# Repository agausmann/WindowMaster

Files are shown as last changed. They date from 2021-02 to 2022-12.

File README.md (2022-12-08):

# WindowMaster

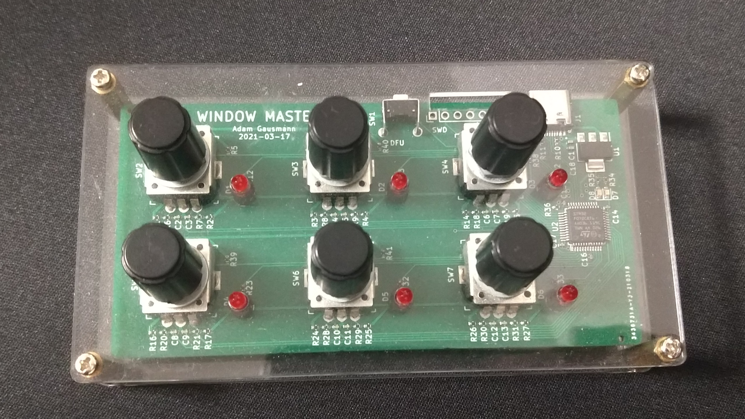
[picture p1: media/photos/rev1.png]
WindowMaster Rev1


A physical controller for the Windows Volume Mixer (sndvol).

This project is made up of multiple hardware and software parts:

- `pcb/` - KiCad design files for the controller PCB.

- `case/` - A laser-cut acrylic case for the PCB.

- `firmware/` - Firmware running on the controller.

- `host-controller/` (**WIP**) - PC software to bridge between the controller
  and the system volume mixer.

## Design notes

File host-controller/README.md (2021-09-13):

# Host Controller Software

**This is a Work in Progress.** The core of the application is nearly complete, but I would not
consider it ready for general use, because it is lacking GUI elements that are very important for
a good user experience.

However, if you would like to try it out, you can run it on the command line. You will, of course,
need a WindowMaster device to interface with the application (though support for MIDI control
surfaces may come in the future).

Make sure you have the [Rust toolchain](https://www.rust-lang.org/tools/install) installed, and
then clone and run with:

```sh
git clone https://github.com/agausmann/windowmaster.git
cd windowmaster/host-controller
cargo run
```

You can set bindings on each channel by pressing the knob down until its LED starts blinking.
The menu will be printed on the console. Navigate by rotating the knob, and select by pressing.
Then, the knob can be used to control the volume and mute of that device or application.
Long-press again at any time to open the menu and re-bind the channel.

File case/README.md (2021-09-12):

# Case Files

The case is made from two laser-cut acrylic parts, the top and bottom plate.
The top plate has holes for the encoders, LEDs, and the ST-Link header, and it
is mounted to the PCB by the fasteners on the encoder stems. The bottom plate
has holes to access the DFU/Reset buttons on the back of the PCB, and is
attached to the front plate with M2.5 bolts and 15mm standoffs.

I've provided the OpenSCAD models and the SVGs generated from them, one for the
top plate, and one for the bottom plate. The SVGs can be provided to a
laser-cutting service like Ponoko; I'd recommend using 2mm clear acrylic
sheets. The dimensions in the SVG files are in millimeters.

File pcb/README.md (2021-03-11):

# WindowMaster PCB

This circuit board is the main board for the WindowMaster physcial controller.
It supports 6 control channels which can be individually assigned to different
channels via the WindowMaster software.

The MCU powering this board is an [STM32F072C8], which can read the encoder
states and set indicators via GPIO, and communicate with the host computer over
USB. You can flash the provided firmware to communicate with and control the
WindowMaster host software, or write and flash your own if you have another
usecase for the control surface. (In the future, I may provide other firmwares
to turn it into a generic input device like a joystick or MIDI. Feel free to
contact me if you'd like to commission a custom firmware - I'd love to hear
about your idea!)

This board is developed with KiCad version 5.1.9. Components, especially those
that can or must be surface-mounted, are picked from the [JLCPCB SMT Parts
Library](https://jlcpcb.com/parts), if there is a suitable part there. This
makes it more convenient to fabricate and assemble, as they will do most of the
work. Everything else is picked to be easy to hand-solder with an iron, which
generally means through-hole or large tabs.

## Ordering

TODO

## Programming Reference & Pinout

The PCB is laid out into six channels. Each channel has its own quadrature
encoder (PEC11R), a pushbutton switch (built into the encoder), and an
indicator LED. These peripherals are controlled by the onboard [STM32F072C8]
microcontroller, which is also given a USB port so it can communicate with a
host system.

Here is the pinout of the STM32 chip to all of its connected peripherals, for
quick reference while programming:

| Physical | Logical | Description | Direction | Logic |
|---|---|---|---|---|
| 25 | PB12 | Status LED | Output | Active Low |
| 32 | PA11 | USB D- | | |
| 33 | PA12 | USB D+ | | |
| 3 | PC14 | Channel 1 Encoder A  | Input | Active Low |
| 2 | PC13 | Channel 1 Encoder B  | Input | Active Low |
| 39 | PB3 | Channel 1 Pushbutton | Input | Active Low |
| 40 | PB4 | Channel 1 Indicator  | Output | Active Low |
| 46 | PB9 | Channel 2 Encoder A  | Input | Active Low |
| 45 | PB8 | Channel 2 Encoder B  | Input | Active Low |
| 38 | PA15 | Channel 2 Pushbutton | Input | Active Low |
| 41 | PB5 | Channel 2 Indicator  | Output | Active Low |
| 43 | PB7 | Channel 3 Encoder A  | Input | Active Low |
| 42 | PB6 | Channel 3 Encoder B  | Input | Active Low |
| 27 | PB14 | Channel 3 Pushbutton | Input | Active Low |
| 28 | PB15 | Channel 3 Indicator  | Output | Active Low |
| 18 | PB0 | Channel 4 Encoder A  | Input | Active Low |
| 17 | PA7 | Channel 4 Encoder B  | Input | Active Low |
| 6 | PF1 | Channel 4 Pushbutton | Input | Active Low |
| 10 | PA0 | Channel 4 Indicator  | Output | Active Low |
| 16 | PA6 | Channel 5 Encoder A  | Input | Active Low |
| 15 | PA5 | Channel 5 Encoder B  | Input | Active Low |
| 5 | PF0 | Channel 5 Pushbutton | Input | Active Low |
| 11 | PA1 | Channel 5 Indicator  | Output | Active Low |
| 14 | PA4 | Channel 6 Encoder A  | Input | Active Low |
| 13 | PA3 | Channel 6 Encoder B  | Input | Active Low |
| 4 | PC15 | Channel 6 Pushbutton | Input | Active Low |
| 12 | PA2 | Channel 6 Indicator  | Output | Active Low |

## Flashing

The focus of this section will be on the specifics of flashing on this board. I
expect the reader to know generally how to program STM32 devices; there's plenty
of other resources on the Internet that explain it better than I ever could.

There are two ways that the STM32 chip can be flashed: the USB DFU protocol,
and the ST-Link debug interface.

### USB DFU

To start the device in DFU mode:  While holding down the DFU button, connect
the USB cable so that it powers on and connects to the computer. Once it has
turned on, you can let go of DFU.

(_Note_: If the device is already connected, you can enter DFU mode without
disconnecting by holding down DFU and pressing and releasing RESET. Again, you
can release DFU once it has reset.)

Once the device is in DFU mode, you can use a tool like [DfuSe] or [dfu-util] on
the host computer to connect to the device and flash firmware binaries.

### ST-Link

There is a spot for an ST-Link / SWD breakout header at the top of the PCB, in
between the reset switch and USB port. The pinout of that port is designed to
match the SWD header on Discovery/Nucleo boards, so from left to right:

1. 3v3 power (not connected in rev1, you have to supply power over USB)
2. SWCLK
3. GND
4. SWDIO
5. NRST
6. Not connected (normally SWO, which is unsupported by this chip).

Connect an ST-Link to that header, and connect both the ST-Link and the PCB to
the computer via USB. Then you can flash using whatever ST-Link compatible tool
or method you prefer. (openOCD, cargo-flash, etc)

[STM32F072C8]: https://www.st.com/en/microcontrollers-microprocessors/stm32f072c8.html
[DfuSe]: https://www.st.com/en/development-tools/stsw-stm32080.html#overview
[dfu-util]: http://dfu-util.sourceforge.net/

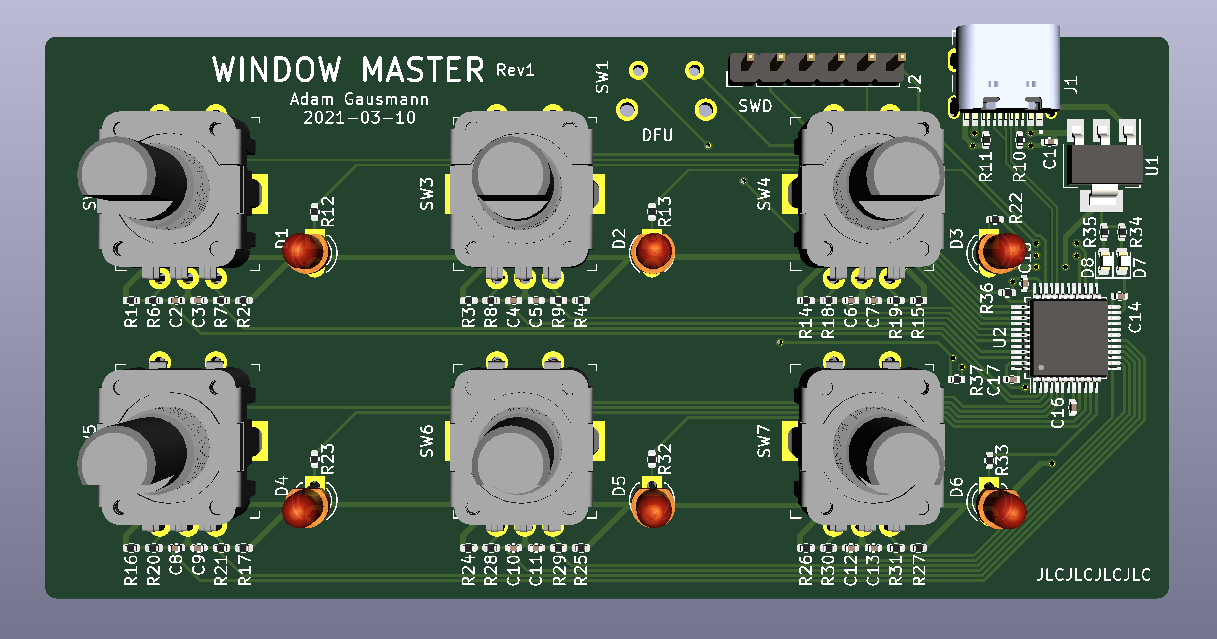
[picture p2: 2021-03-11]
media/renders/pcb-front.png

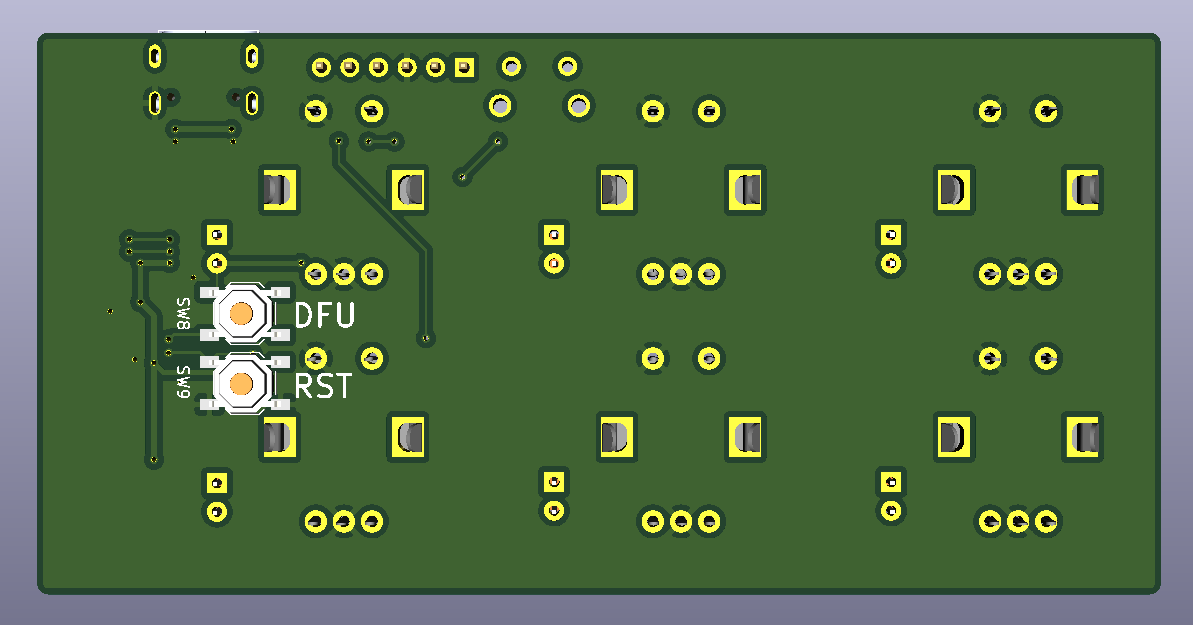
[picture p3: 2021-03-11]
media/renders/pcb-back.png

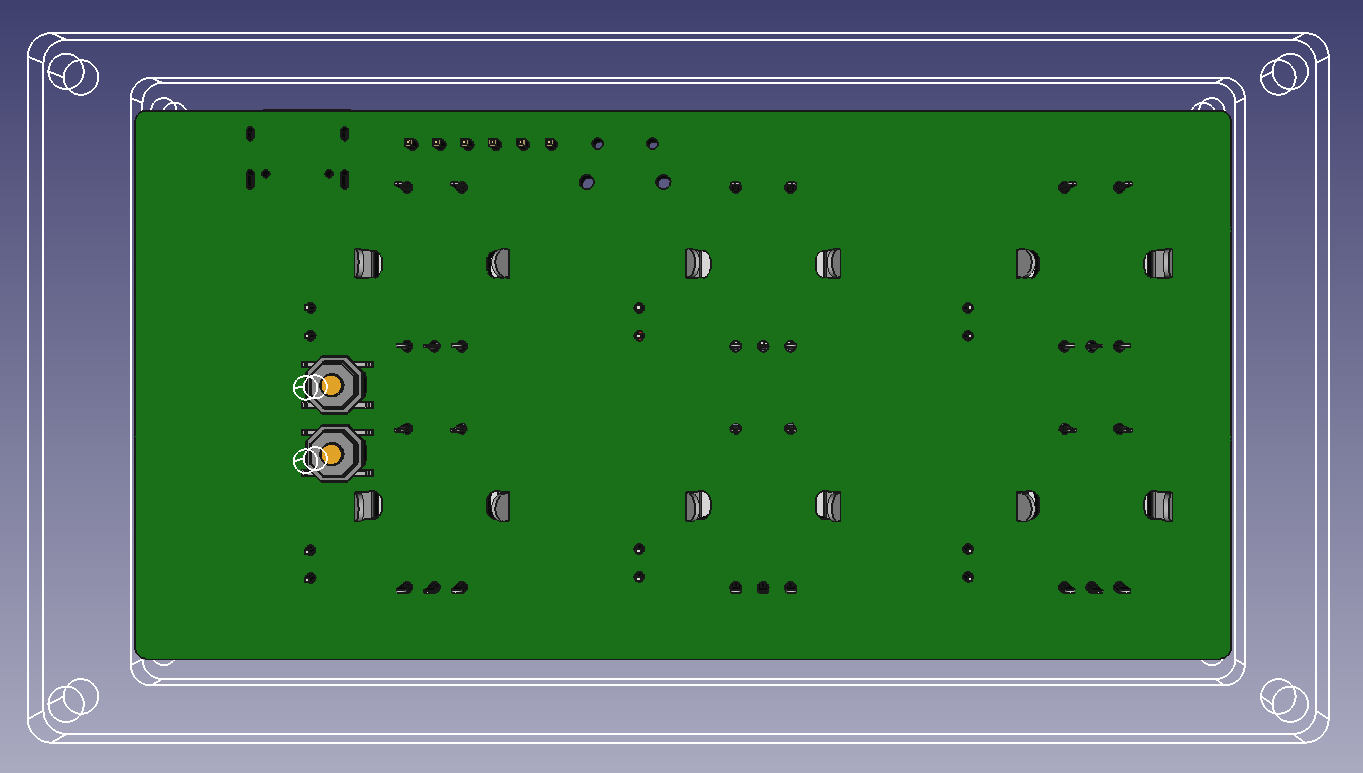
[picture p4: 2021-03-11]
media/renders/cad-back.png

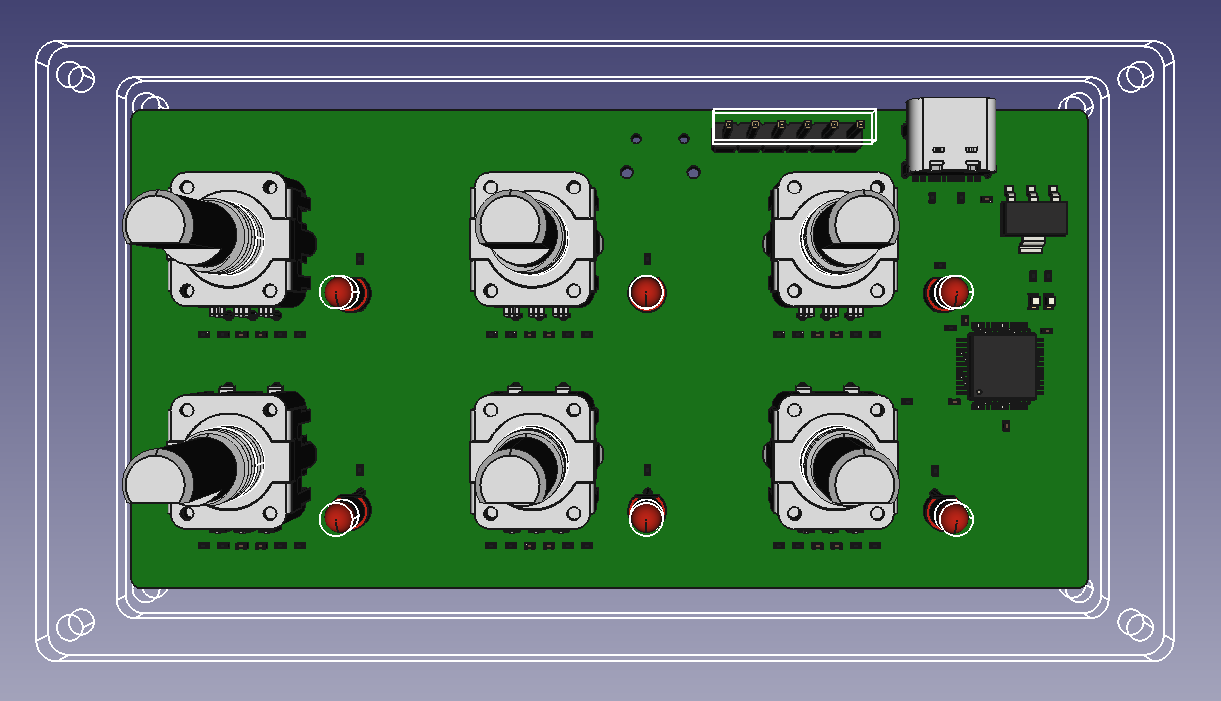
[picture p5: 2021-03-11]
media/renders/cad-front.png

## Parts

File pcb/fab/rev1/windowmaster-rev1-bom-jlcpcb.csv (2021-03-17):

Comment | Designator | Footprint | LCSC Part #
4.7uF | C1,C18 | 0402 | C23733
10nF | C2-13 | 0402 | C15195
100nF | C14-17 | 0402 | C1525
PWR_LED | D7 | 0603 | C72043
STATUS_LED | D8 | 0603 | C72038
USB_C_Receptacle_USB2.0 | J1 |  | C165948
5.1K | R10,R11 | 0402 | C25905
1K | R12, R13, R22, R23, R32-35 | 0402 | C11702
10K | R1-9, R14-21, R24-31, R36-42 | 0402 | C25744
AZ1117-3.3 | U1 | SOT-223 | C108494
STM32F072C8T6 | U2 | LQFP-48_7.0x7.0x0.5P | C80488

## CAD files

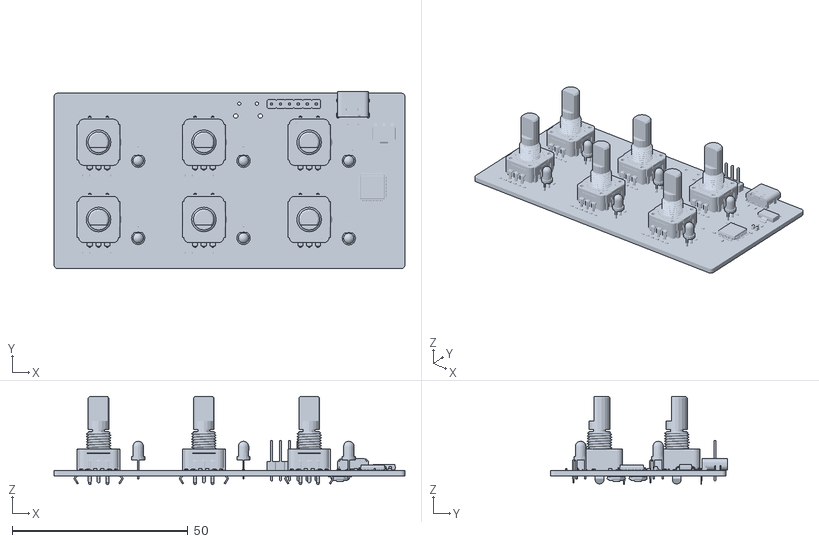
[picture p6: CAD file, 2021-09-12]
case/windowmaster.stl
100.0 x 50.5 x 25.2

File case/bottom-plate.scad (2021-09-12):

use <plate.scad>

$fa = 1;
$fs = 0.4;

module bottom_plate() {
    difference() {
        plate();

        // Reset/DFU button holes
        translate([86.5, 30])
            circle(r=1);
        translate([86.5, 23.5])
            circle(r=1);
    }
}

bottom_plate();

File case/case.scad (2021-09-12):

// A full model (including the PCB model) to demonstrate the assembled case
// and visually verify the plate drawings.
//
// To order parts for this case, use the `top-plate` and `bottom-plate` files
// instead of this model.

use <top-plate.scad>
use <bottom-plate.scad>

plate_thickness = 2;
standoff_height = 15;

module case() {
    color([1, 1, 1, 0.2]) {
        linear_extrude(plate_thickness)
            top_plate();
        translate([0, 0, -(standoff_height + plate_thickness)])
            linear_extrude(plate_thickness)
                bottom_plate();
    }
    translate([55, 30, -8])
        import("windowmaster.stl");
}

case();

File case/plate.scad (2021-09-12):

// Base plate module used for both bottom & top plates.

width = 110;
height = 60;
radius = 2;
screw_radius = 1.25;
screw_inset = 3.25;

module plate() {
    difference() {
        translate([radius, radius])
            minkowski() {
                square([width - 2 * radius, height - 2 * radius]);
                circle(r=radius);
            }

        translate([screw_inset, screw_inset])
            circle(r=screw_radius);        
        translate([screw_inset, height - screw_inset])
            circle(r=screw_radius);
        translate([width - screw_inset, screw_inset])
            circle(r=screw_radius);
        translate([width - screw_inset, height - screw_inset])
            circle(r=screw_radius);
    }
}

plate();

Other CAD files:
pcb/snap_eda/pec11r-4015f-s0024.stp
pcb/windowmaster.step
pcb/snap_eda/TYPE-C-31-M-12.step
case/top-plate.scad

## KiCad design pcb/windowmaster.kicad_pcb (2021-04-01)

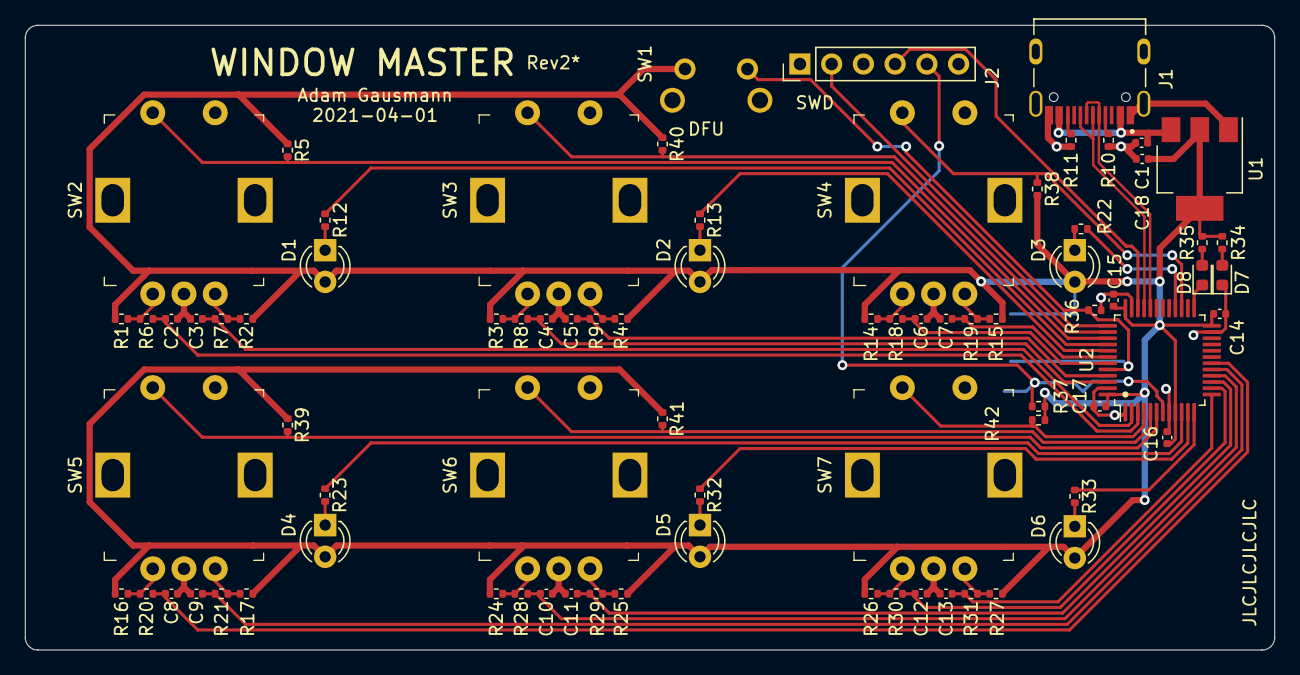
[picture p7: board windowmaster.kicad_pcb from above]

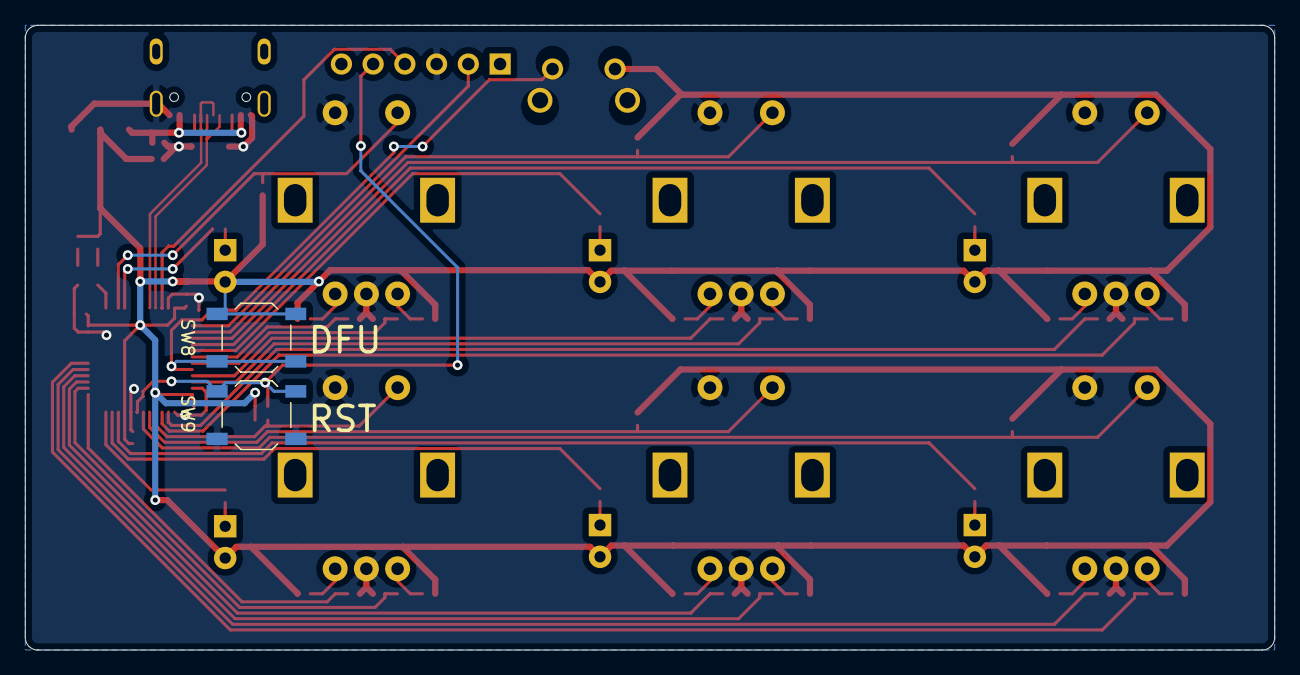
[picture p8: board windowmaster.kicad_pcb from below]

Board: 2 copper layers, 100.0 x 50.0 mm, 81 parts (2 on the bottom side), 56 nets.

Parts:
C1, C18: 4.7uF; C_0402_1005Metric
C2, C3, C4, C5, C6, C7, C8, C9, C10, C11, C12, C13: 10nF; C_0402_1005Metric
C14, C15, C16, C17: 100nF; C_0402_1005Metric
D1, D2, D3, D4, D5, D6: LED; LED_D3.0mm
D7: PWR_LED; LED_0603_1608Metric
D8: STATUS_LED; LED_0603_1608Metric
J1: USB_C_Receptacle_USB2.0; HRO_TYPE-C-31-M-12
J2: SWD; PinHeader_1x06_P2.54mm_Vertical
R1, R2, R3, R4, R5, R6, R7, R8, R9, R14, R15, R16, R17, R18, R19, R20, R21, R24, R25, R26, R27, R28, R29, R30, R31, R36, R37, R38, R39, R40, R41, R42: 10K; R_0402_1005Metric
R10, R11: 5.1K; R_0402_1005Metric
R12, R13, R22, R23, R32, R33, R34, R35: 1K; R_0402_1005Metric
SW1: SW_DFU2; MJTP1117
SW2, SW3, SW4, SW5, SW6, SW7: ENC; Rotary_Encoder_Switched_PEC11R
SW8: SW_DFU; SW_SPST_TL3342
SW9: SW_RST; SW_SPST_TL3342
U1: AZ1117-3.3; SOT-223-3_TabPin2
U2: STM32F072C8T6; LQFP-48_7x7mm_P0.5mm

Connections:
+3V3: C14.1, C15.1, C16.1, C17.1, C18.1, D1.2, D2.2, D3.2, D4.2, D5.2, D6.2, R1.1, R2.1, R3.1, R4.1, R5.1, R14.1, R15.1, R16.1, R17.1, R24.1, R25.1, R26.1, R27.1, R34.1, R35.1, R37.1, R38.1, R39.1, R40.1, R41.1, R42.1, SW1.2, SW8.1, U1.2, U2.9, U2.24, U2.36, U2.48
DFU: R36.1, SW1.1, SW8.2, U2.44
ENC_1A: C2.1, R6.2, U2.3
ENC_1B: C3.1, R7.2, U2.2
ENC_2A: C4.1, R8.2, U2.46
ENC_2B: C5.1, R9.2, U2.45
ENC_3A: C6.1, R18.2, U2.43
ENC_3B: C7.1, R19.2, U2.42
ENC_4A: C8.1, R20.2, U2.18
ENC_4B: C9.1, R21.2, U2.17
ENC_5A: C10.1, R28.2, U2.16
ENC_5B: C11.1, R29.2, U2.15
ENC_6A: C12.1, R30.2, U2.14
ENC_6B: C13.1, R31.2, U2.13
GND: C1.2, C2.2, C3.2, C4.2, C5.2, C6.2, C7.2, C8.2, C9.2, C10.2, C11.2, C12.2, C13.2, C14.2, C15.2, C16.2, C17.2, C18.2, D7.1, J1.A1, J1.A12, J1.B1, J1.B12, J1.S1, J2.3, R10.1, R11.1, R36.2, SW2.C, SW2.S2, SW3.C, SW3.S2, SW4.C, SW4.S2, SW5.C, SW5.S2, SW6.C, SW6.S2, SW7.C, SW7.S2, SW9.2, U1.1, U2.1, U2.8, U2.23, U2.35, U2.47
IND_1: R12.1, U2.40
IND_2: R13.1, U2.41
IND_3: R22.1, U2.28
IND_4: R23.1, U2.10
IND_5: R32.1, U2.11
IND_6: R33.1, U2.12
NRST: J2.5, R37.2, SW9.1, U2.7
unnamed: D1.1, R12.2
unnamed: D2.1, R13.2
unnamed: D3.1, R22.2
unnamed: D4.1, R23.2
unnamed: D5.1, R32.2
unnamed: D6.1, R33.2
unnamed: D7.2, R34.2
unnamed: D8.2, R35.2
unnamed: J1.A5, R10.2
unnamed: J1.B5, R11.2
unnamed: R1.2, R6.1, SW2.A
unnamed: R2.2, R7.1, SW2.B
unnamed: R3.2, R8.1, SW3.A
unnamed: R4.2, R9.1, SW3.B
unnamed: R14.2, R18.1, SW4.A
unnamed: R15.2, R19.1, SW4.B
unnamed: R16.2, R20.1, SW5.A
unnamed: R17.2, R21.1, SW5.B
unnamed: R24.2, R28.1, SW6.A
unnamed: R25.2, R29.1, SW6.B
unnamed: R26.2, R30.1, SW7.A
unnamed: R27.2, R31.1, SW7.B
STATUS: D8.1, U2.25
SWCLK: J2.2, U2.37
SWDIO: J2.4, U2.34
SW_1: R5.2, SW2.S1, U2.39
SW_2: R40.2, SW3.S1, U2.38
SW_3: R38.2, SW4.S1, U2.27
SW_4: R39.2, SW5.S1, U2.6
SW_5: R41.2, SW6.S1, U2.5
SW_6: R42.2, SW7.S1, U2.4
USB_D+: J1.A6, J1.B6, U2.33
USB_D-: J1.A7, J1.B7, U2.32
VBUS: C1.1, J1.A4, J1.A9, J1.B4, J1.B9, U1.3

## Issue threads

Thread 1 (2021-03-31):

Rev1 PCB design problems

agausmann, 2021-03-31:
- [ ] LEDs blink on poweron, because they're wired active-low and the pin goes low for a moment when set to output mode.
- [ ] Status LEDs are too bright

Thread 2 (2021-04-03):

PEC11R quality issue

agausmann, 2021-04-03:
The shaft of the PEC11R encoder has a noticeable amount of wobble. I should try out some other encoders for the next revision, see if there are better options that fit my needs.

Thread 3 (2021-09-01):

Premium/deluxe control surface

agausmann, 2021-09-01:
The current hardware was designed on a budget. I'd like to keep and maintain that as an option, but I would also like to design and produce a more high-quality device in the future.

Features I'm thinking about incorporating:

- Motorized faders
- Dedicated buttons for mute and navigation
- Integrated LCD display(s) which can be used to display labels and menus

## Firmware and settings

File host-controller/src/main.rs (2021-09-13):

use windowmaster::{
    backend::{hidapi::HidApiControlBackend, windows::WindowsAudioBackend},
    core::Core,
};

pub fn main() -> anyhow::Result<()> {
    env_logger::init();

    Core::new(WindowsAudioBackend::new(), HidApiControlBackend)
        .run()
        .map_err(|e| anyhow::anyhow!("{}", e))?;

    Ok(())
}

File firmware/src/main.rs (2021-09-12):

#![no_std]
#![cfg_attr(not(test), no_main)]
#![feature(default_alloc_error_handler)]

use alloc_cortex_m::CortexMHeap;
use core::panic::PanicInfo;
use cortex_m::interrupt::free as interrupt_free;
use cortex_m::prelude::*;
use cortex_m_rt as rt;
use stm32f0xx_hal::stm32;
use windowmaster_firmware::indicator::Indicator;

// Pick a system definition here:

use windowmaster_firmware::system::rev1 as system;
//use windowmaster_firmware::system::discovery as system;

use system::{PanicSystem, System};

#[global_allocator]
static ALLOCATOR: CortexMHeap = CortexMHeap::empty();

#[panic_handler]
fn panic(info: &PanicInfo) -> ! {
    // We are in an unrecoverable error state.
    // The regular program is not going to resume, so it is safe to take control of peripherals.
    // There might be problems here, since some of the peripherals may not be in their
    // reset state, like the PAC might assume, but I _think_ it's okay as long as the pin modes are
    // explicitly set somewhere before being used.
    let dp = unsafe { stm32::Peripherals::steal() };
    let cp = unsafe { stm32::CorePeripherals::steal() };

    let mut system = interrupt_free(|cs| PanicSystem::new(dp, cp, cs));

    system.status_led().turn_off().ok();
    for _ in 0..4 {
        system.delay().delay_ms(200u32);
        system.status_led().turn_on().ok();
        system.delay().delay_ms(200u32);
        system.status_led().turn_off().ok();
    }

    //TODO log error via debugger.
    // writing via cortex_m_semihosting tends to hang in my testing - need to look into that.

    // Error has been logged, reset the system.
    system.delay().delay_ms(1000u32);
    stm32::SCB::sys_reset()
}

#[cfg(not(test))]
#[rt::entry]
fn main() -> ! {
    let heap_start = cortex_m_rt::heap_start() as usize;
    let heap_size = 1024;
    unsafe { ALLOCATOR.init(heap_start, heap_size) }

    let dp = stm32::Peripherals::take().unwrap();
    let cp = stm32::CorePeripherals::take().unwrap();

    let mut system = interrupt_free(|cs| System::new(dp, cp, cs));
    system.run();
}

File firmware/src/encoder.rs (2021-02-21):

use core::convert::Infallible;
use embedded_hal::digital::v2::InputPin;

/// A relative, incremental encoder that can detect and report single steps forward and backward.
pub trait Encoder {
    type Error;

    /// Polls the encoder for updates, and returns the resulting step, if any.
    fn poll(&mut self) -> Result<Step, Self::Error>;
}

/// A step increment returned by an [`Encoder`].
#[derive(Debug, Clone, Copy, PartialEq, Eq)]
pub enum Step {
    None,
    Backward,
    Forward,
}

impl Step {
    pub fn value(self) -> i8 {
        match self {
            Self::None => 0,
            Self::Backward => -1,
            Self::Forward => 1,
        }
    }
}

/// A quadrature encoder peripheral.
pub struct Quadrature<A, B> {
    pin_a: A,
    pin_b: B,
    old_index: Option<i8>,
}

impl<A, B> Quadrature<A, B> {
    /// Creates a new encoder from the given input pins.
    pub fn new(pin_a: A, pin_b: B) -> Self {
        Self {
            pin_a,
            pin_b,
            old_index: None,
        }
    }
}

impl<A, B> Encoder for Quadrature<A, B>
where
    A: InputPin,
    B: InputPin,
{
    type Error = Error<A::Error, B::Error>;

    fn poll(&mut self) -> Result<Step, Self::Error> {
        let a = self.pin_a.is_high().map_err(Error::PinA)?;
        let b = self.pin_b.is_high().map_err(Error::PinB)?;
        let new_index = index(a, b);

        let result = if let Some(old_index) = self.old_index {
            match (new_index + (4 - old_index)) % 4 {
                0 => Ok(Step::None),
                1 => Ok(Step::Forward),
                2 => Err(Error::Skipped),
                3 => Ok(Step::Backward),
                _ => unreachable!(),
            }
        } else {
            Ok(Step::None)
        };
        self.old_index = Some(new_index);
        result
    }
}

fn index(a: bool, b: bool) -> i8 {
    match (a, b) {
        (false, false) => 0,
        (true, false) => 1,
        (true, true) => 2,
        (false, true) => 3,
    }
}

#[derive(Debug)]
pub enum Error<A, B> {
    /// An error that occurred while reading Pin A.
    PinA(A),

    /// An error that occurred while reading Pin B.
    PinB(B),

    /// A skipped step was detected.
    Skipped,
}

#[derive(Default)]
pub struct Disabled;

impl Encoder for Disabled {
    type Error = Infallible;

    fn poll(&mut self) -> Result<Step, Self::Error> {
        Ok(Step::None)
    }
}

#[cfg(test)]
mod tests {
    use super::*;
    use embedded_hal_mock::pin;
    use embedded_hal_mock::pin::Transaction;
    use embedded_hal_mock::{High, Low};
    use Step::{Backward, Forward, None};

    fn assert_polls(pin_a: &[pin::Transaction], pin_b: &[pin::Transaction], polls: &[Step]) {
        let mut pin_a = pin::Mock::new(pin_a);
        let mut pin_b = pin::Mock::new(pin_b);
        let mut encoder = Encoder::new(pin_a.clone(), pin_b.clone());
        for &value in polls {
            assert_eq!(encoder.poll().unwrap(), value);
        }
        pin_a.done();
        pin_b.done();
    }

    #[test]
    fn forward() {
        assert_polls(
            &[
                Transaction::get(Low),
                Transaction::get(High),
                Transaction::get(High),
                Transaction::get(Low),
                Transaction::get(Low),
            ],
            &[
                Transaction::get(Low),
                Transaction::get(Low),
                Transaction::get(High),
                Transaction::get(High),
                Transaction::get(Low),
            ],
            &[None, Forward, Forward, Forward, Forward],
        );
    }

    #[test]
    fn backward() {
        assert_polls(
            &[
                Transaction::get(Low),
                Transaction::get(Low),
                Transaction::get(High),
                Transaction::get(High),
                Transaction::get(Low),
            ],
            &[
                Transaction::get(Low),
                Transaction::get(High),
                Transaction::get(High),
                Transaction::get(Low),
                Transaction::get(Low),
            ],
            &[None, Backward, Backward, Backward, Backward],
        );
    }

    #[test]
    #[should_panic]
    fn skipped() {
        assert_polls(
            &[Transaction::get(Low), Transaction::get(High)],
            &[Transaction::get(Low), Transaction::get(High)],
            &[None, Forward],
        );
    }
}

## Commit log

2021-02-04 Make a subdirectory for PCB design files
    [pec11r-4015f-s0024.stp, windowmaster.kicad_pcb, windowmaster.sch]
2021-02-05 Add relevant part numbers and datasheets to schematic
    [windowmaster.sch]
2021-02-05 Reset silkscreen labels
    [windowmaster.kicad_pcb]
2021-02-06 Rearrange vias to cut less into ground plane
    [windowmaster.kicad_pcb]
2021-02-11 Add USB device dependencies
2021-02-13 Separate the USB/MCU/power supply parts of the schematic
    [windowmaster.kicad_pcb, windowmaster.sch]
2021-02-16 USB PID registered!
2021-02-20 Changes from testing channels and USB on dev board
2021-02-21 Read LED state from output reports
2021-02-21 Add custom panic handler with LED pattern
2021-02-22 Add reset switch models to PCB and add case draft
    [case.FCStd, windowmaster.kicad_pcb, windowmaster.sch]
2021-02-22 Add switch labels on PCB
    [windowmaster.kicad_pcb]
2021-03-11 Hierarchical redesign and add ST-Link SWD header
    [TYPE-C-31-M-12.step, channel.sch, windowmaster.kicad_pcb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]
2021-03-11 Add rev1 case files
    [case.FCStd]
2021-03-11 Update CAD models and add renders
    [case.FCStd]
2021-03-11 Add programming/flashing instructions for PCB
2021-03-12 Rough PoC of audio device/app enumeration on Windows
2021-03-13 Add USB HID device enumeration
2021-03-17 Migrate to Git LFS
    [TYPE-C-31-M-12.step, case.FCStd, pec11r-4015f-s0024.stp]
2021-03-17 Final changes to PCB before ordering...
    - Add external pull-ups to switch inputs.
    - Double-check and fix LCSC part numbers.
    - Add filter capacitor to regulator output.
    [channel.sch, windowmaster.kicad_pcb, windowmaster.sch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]
2021-03-17 Add fabrication files from rev1 1st run
    [windowmaster-rev1-bom-jlcpcb.csv, windowmaster.kicad_pcb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]
2021-03-22 Fix firmware compile error
    [system.rs]
2021-03-22 Read/write HID reports to devices
2021-03-23 Store device state and translate to/from HID reports
2021-04-01 Initialize indicators to "off" state as early as possible
    Prevents a momentary blink that used to happen at startup - since the
    LEDs are wired active-low and they start in low state when changed to
    output mode, if they aren't immediately set high, they will be "on"
    until their next update.
2021-04-01 Switch to Rev1 PCB system by default.
    Rev1 PCBs have arrived! So I'll be primarily using them to test instead
    of the Discovery board.
2021-04-01 Add startup sequence to the status LED.
2021-04-01 Fix MJTP1117 footprint
    [windowmaster.kicad_pcb]
2021-04-01 Add central app manager and device control threads
2021-09-05 hid: Prevent crashing when device is disconnected
2021-09-12 Replace FreeCAD models with OpenSCAD
    [bottom-plate.scad, case.scad, plate.scad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]
2021-09-12 Actually remove FreeCAD model this time
    [case.FCStd]
2021-09-12 Add default device binding
2021-09-12 windows: Implement default audio devices
2021-09-13 Propagate stream state updates for default device bindings
2022-12-08 Add photo of built device
